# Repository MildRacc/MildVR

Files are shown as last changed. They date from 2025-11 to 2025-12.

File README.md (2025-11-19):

# MildVR

MildVR is a completely open-source VR headset with Windows, Linux, and macOS support in mind front the get-go. The goal of this project is to move away from the closed ecosystems of major VR companies like Meta. With the Quest lineup, Meta forces users to make accounts and limits PCVR usage to Windows by keeping their runtime proprietary. That means anyone using macOS or Linux is locked out completely. MildVR is different. It will use the open-source Monado runtime, which works across all three major desktop operating systems. It will never require and account, sign-in, or any proprietary software to function. Every part of the project, from the headset hardware, to the controllers, to the source code, will all be open for anyone to study, modify, or improve. My ultimate goal is to create a VR headset that anyone can build, understand, and use freely without being tied to any company, operating system, or proprietary software.

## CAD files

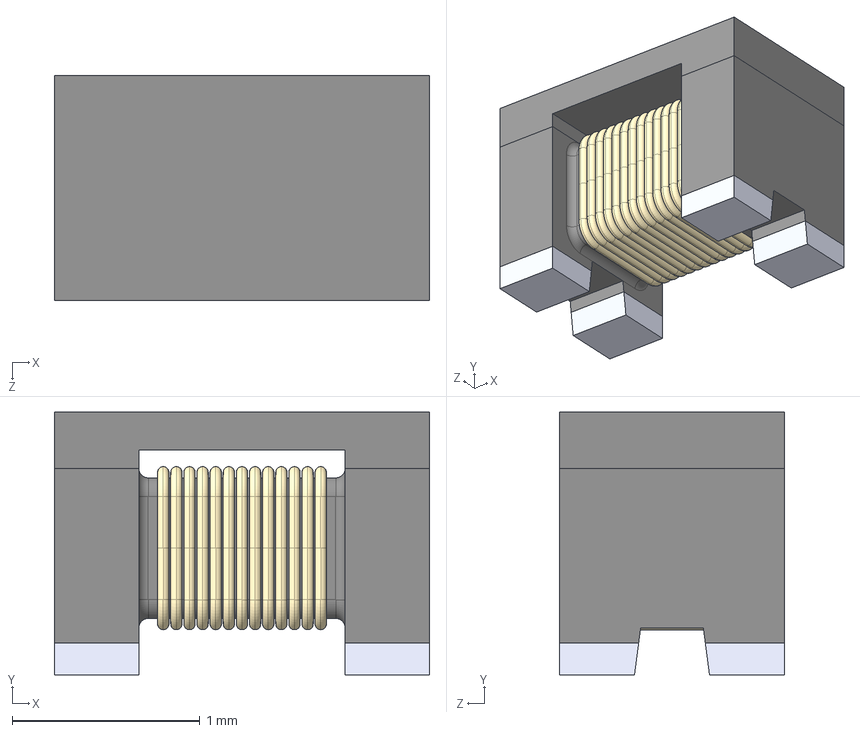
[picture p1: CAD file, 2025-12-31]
PCB/Imports/(CMC)DLW21SZ900HQ2L/DLW21SZ900HQ2L.step
2.00 x 1.40 x 1.20 mm

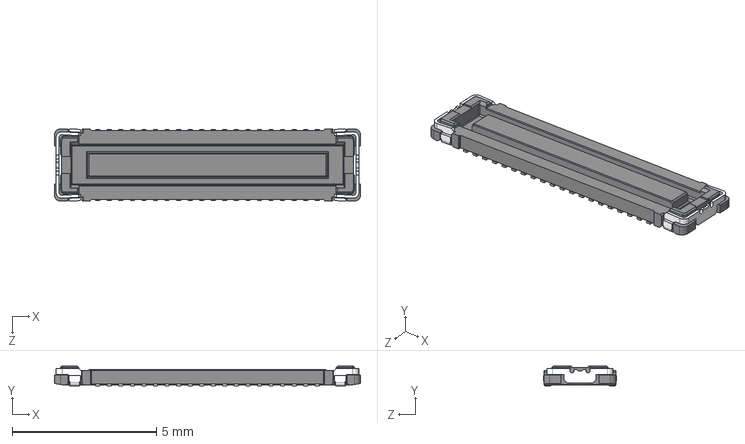
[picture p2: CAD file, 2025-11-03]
PCB/Imports/(DSI) WP7B-S040VA1-R6000/WP7B-S040VA1-R6000.step
10.6 x 0.68 x 2.51 mm

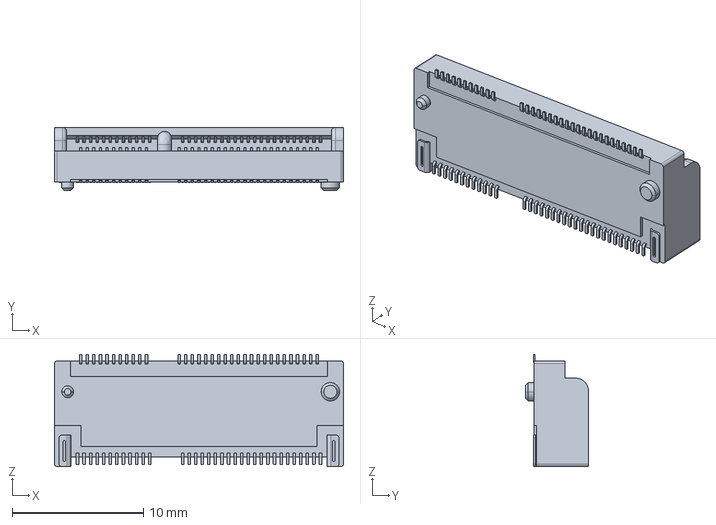
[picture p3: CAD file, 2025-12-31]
PCB/Imports/(PCIe)MDT420E03001/MDT420E03001.step
22.0 x 4.80 x 8.55 mm

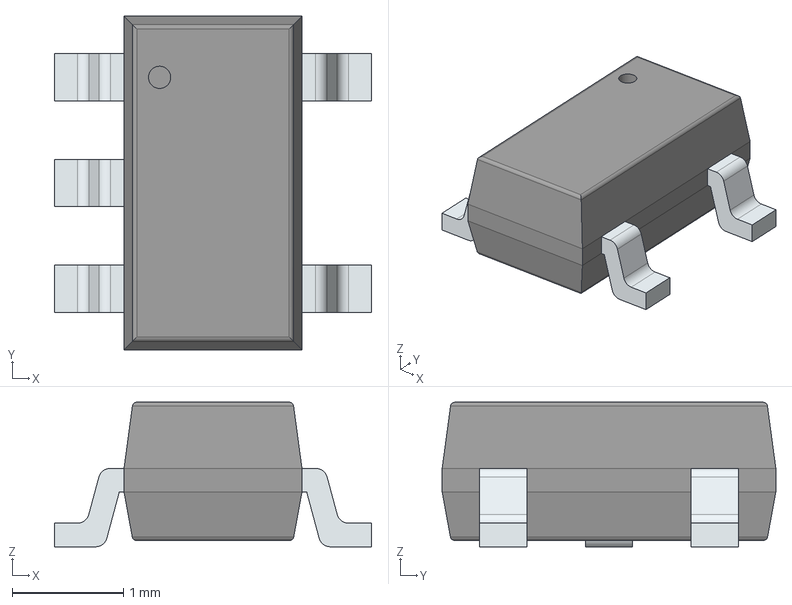
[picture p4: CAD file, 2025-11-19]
PCB/Imports/AP7365-WG-7/AP7365-WG-7/3D/AP7365-WG-7.stp
2.85 x 3.00 x 1.30 mm
PinsArrayL
PinsArrayR

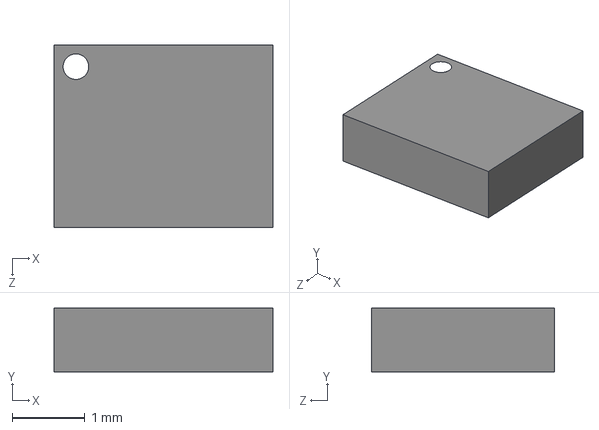
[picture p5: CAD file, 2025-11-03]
PCB/Imports/BMI270/BMI270.step
3.00 x 0.87 x 2.50 mm

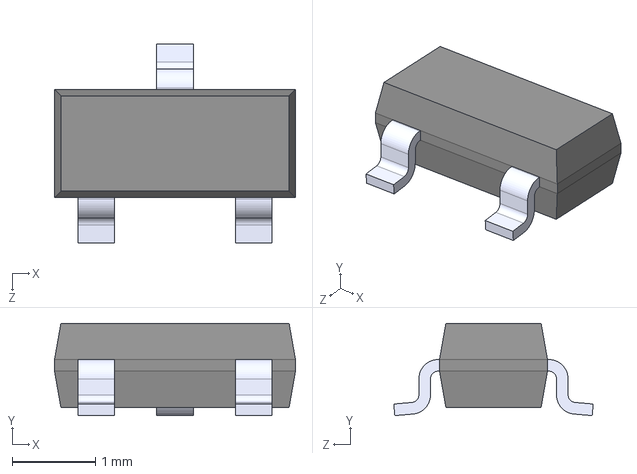
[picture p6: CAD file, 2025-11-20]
PCB/Imports/BSS138/BSS138.step
2.90 x 1.11 x 2.40 mm

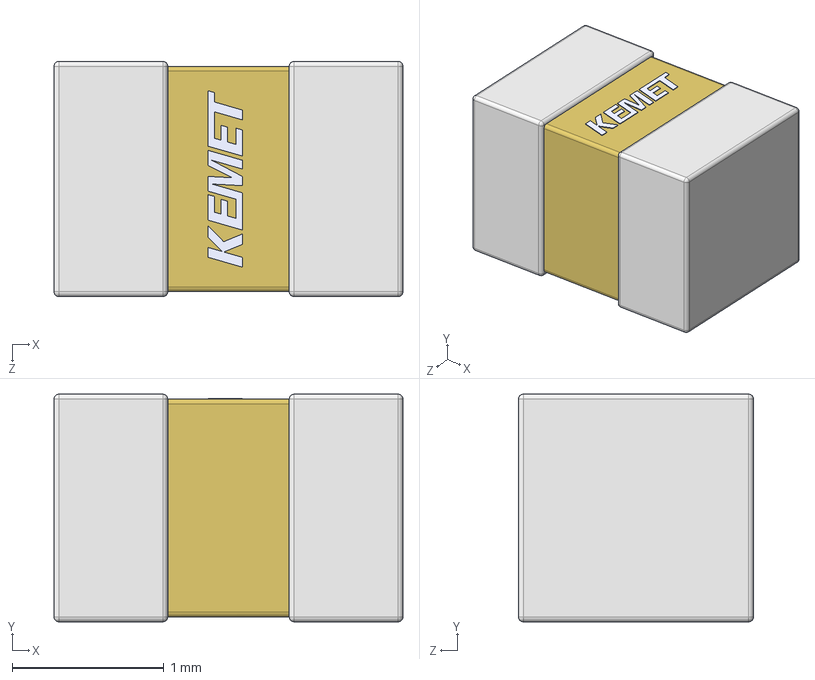
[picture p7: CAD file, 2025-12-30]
PCB/Imports/C0805J105K4RACAUTO(1uF)/C0805J105K4RACAUTO/3D/C0805J105K4RACAUTO.stp
2.30 x 1.50 x 1.55 mm

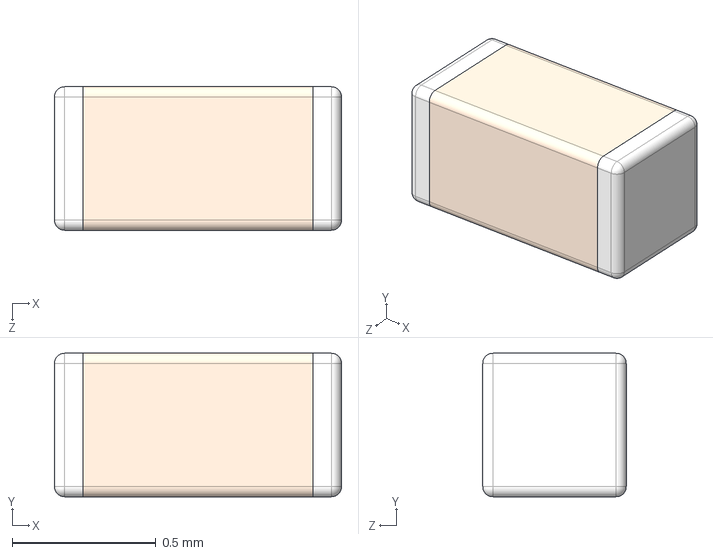
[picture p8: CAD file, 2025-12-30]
PCB/Imports/C1005NP01H102J050BA(1nF)/C1005NP01H102J050BA/3D/C1005NP01H102J050BA.stp
1.00 x 0.5 x 0.5 mm

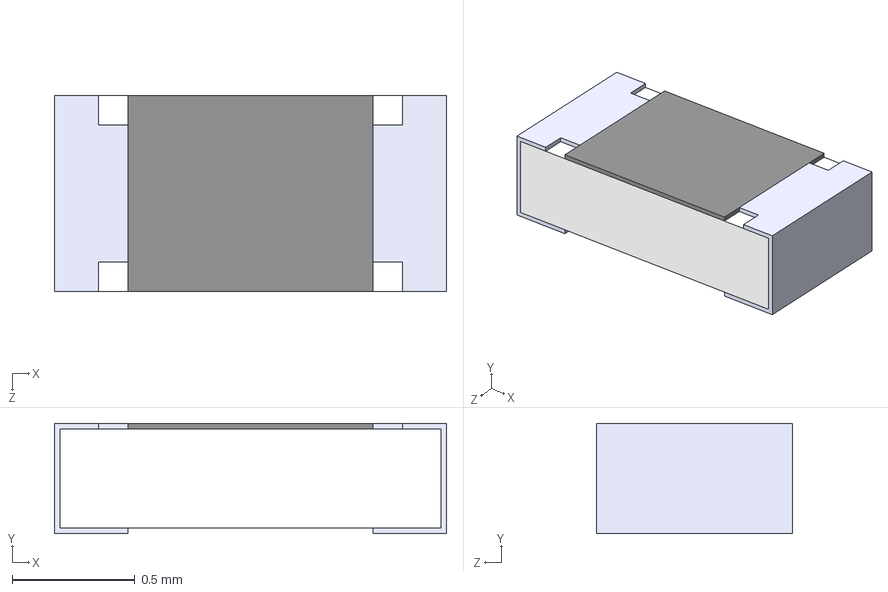
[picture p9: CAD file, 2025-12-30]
PCB/Imports/ERJU03J160V/ERJU03J160V.step
1.60 x 0.45 x 0.8 mm

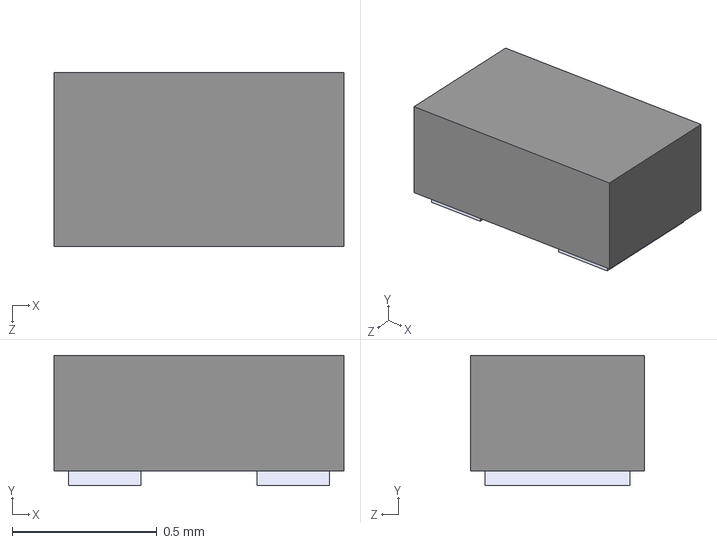
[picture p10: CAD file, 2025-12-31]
PCB/Imports/ESD401DPYR/ESD401DPYR.step
1.00 x 0.45 x 0.6 mm

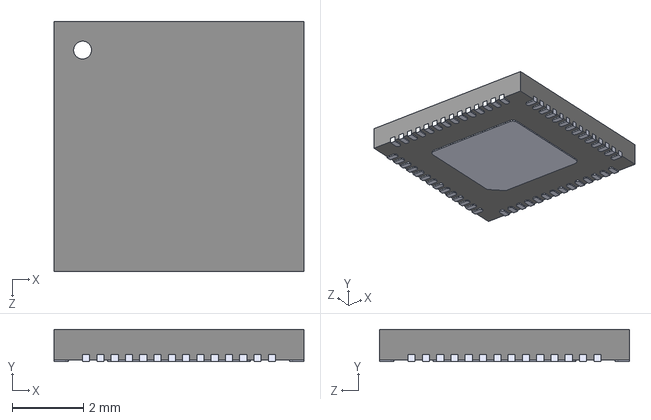
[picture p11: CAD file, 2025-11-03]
PCB/Imports/ESP32-S3/ESP32-S3.step
7.00 x 0.9 x 7.00 mm

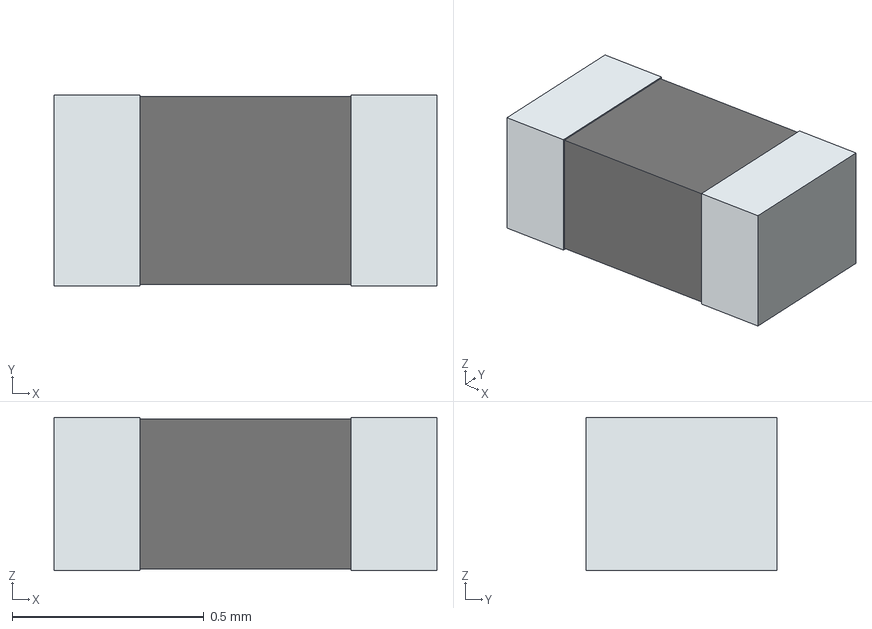
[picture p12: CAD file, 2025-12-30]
PCB/Imports/ESR01MZPF4701(4.7k)/ESR01MZPF4701/3D/ESR01MZPF4701.stp
1.00 x 0.5 x 0.4 mm
term1
term2

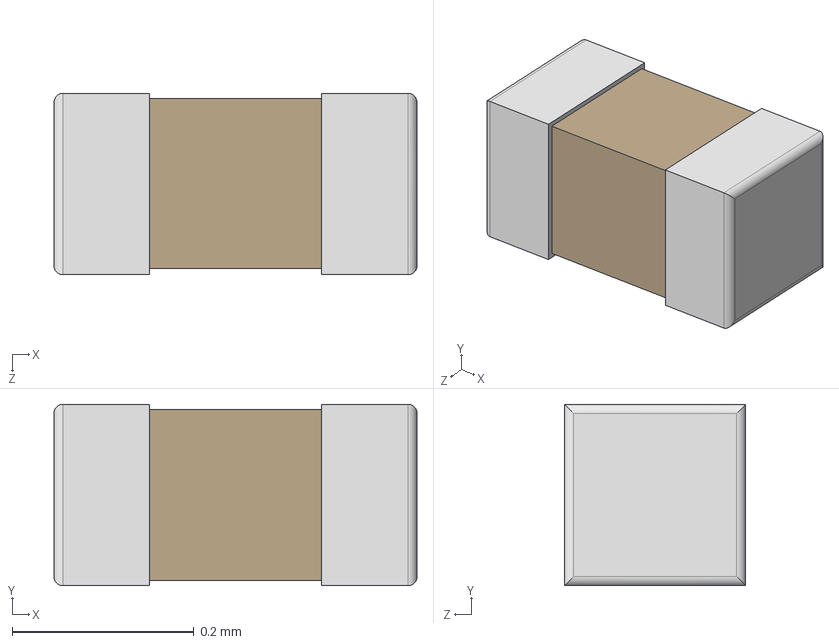
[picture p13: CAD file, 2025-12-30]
PCB/Imports/GRM022C81C103ME01L(10nF)/GRM022C81C103ME01L/3D/GRM022C81C103ME01L.stp
0.4 x 0.2 x 0.2 mm
GRM022R61C104ME05L_1
GRM022R61C104ME05L_2
GRM022R61C104ME05L_3

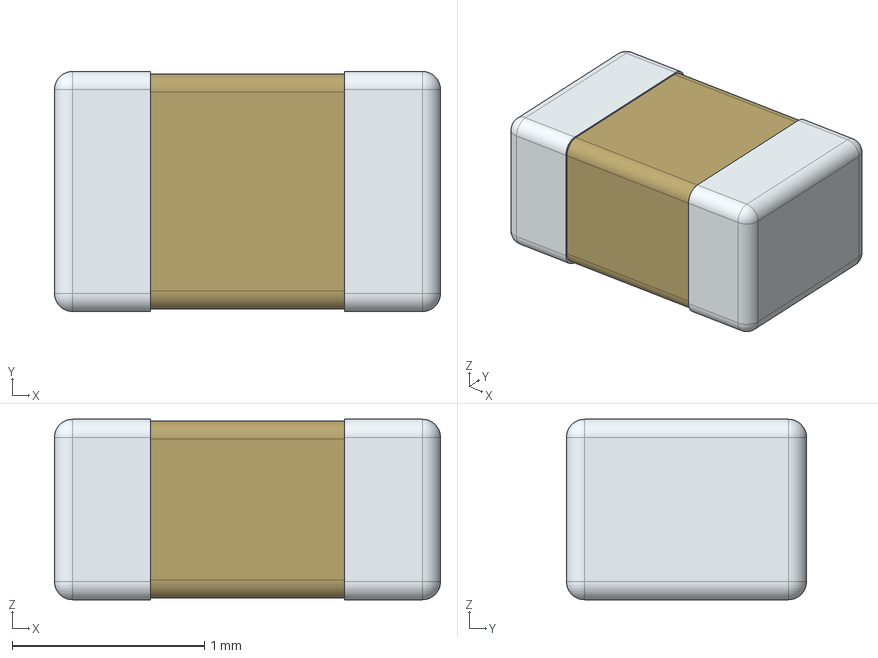
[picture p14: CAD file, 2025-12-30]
PCB/Imports/KAF21BR71H104JM(100nF)/KAF21BR71H104JM/3D/KAF21BR71H104JM.stp
2.01 x 1.25 x 0.94 mm

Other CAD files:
PCB/Imports/SFH_4556/SFH_4556.step
PCB/Imports/(CSI) 20539-050E-01/20539-050E-01.step
PCB/Imports/(Pump)LM27761DSGR/LM27761DSGR.step
PCB/Imports/BMI270/3D/BMI270.stp

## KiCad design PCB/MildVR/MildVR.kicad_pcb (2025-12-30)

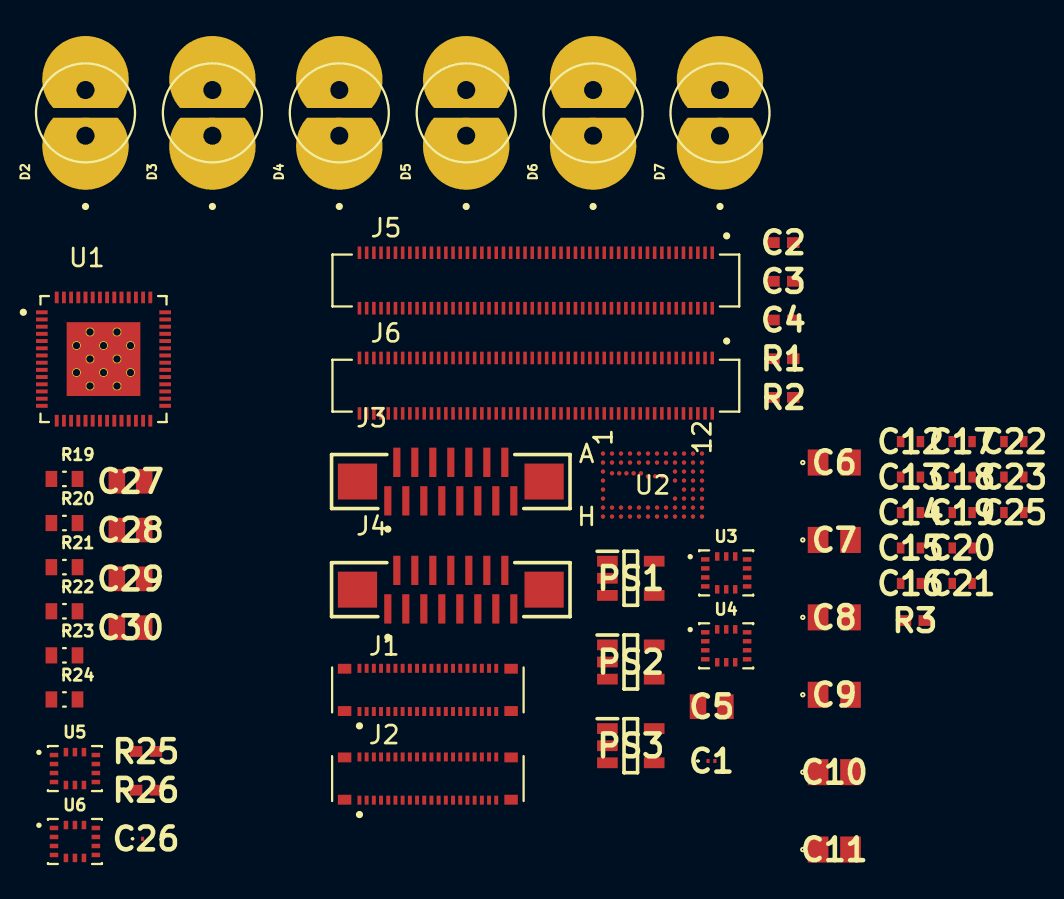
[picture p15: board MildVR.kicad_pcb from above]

Board: 2 copper layers, 61 parts (0 on the bottom side), 41 nets, no tracks yet.

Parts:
C1, C26: 10nF; GRM022C81C222KE01L
C2, C3, C4: 100nF; RESC1005X40N
C5, C27, C28, C29, C30: 100nF; CAPC2012X94L
C6, C7, C8, C9, C10, C11: 1uF; C0805
C12, C13, C14, C15, C16, C17, C18, C19, C20, C21, C22: 1nF; CAPC1005X55N
C23, C25: 100nF; CAPC1005X55N
D2, D3, D4, D5, D6, D7: LED; DIO_SFH_4556
J1, J2: WP7B-S040VA1-R6000; (DSI) WP7B-S040VA1-R6000
J3: CAM1; SAMTEC_ZF5S-15-03-T-WT
J4: CAM2; SAMTEC_ZF5S-15-03-T-WT
J5: GPIO; HIROSE_DF40C-100DS-0.4V_51_
J6: High Speed Serial; HIROSE_DF40C-100DS-0.4V_51_
PS1, PS2, PS3: AP7365-WG-7
R1, R2, R3, R25, R26: 4.7k; RESC1005X40N
R19, R20, R21, R22, R23, R24: 16; RES_ERJU03J160V
U1: ESP32-S3
U2: HMC6301BG46
U3, U4, U5, U6: BMI270

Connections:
1.2V: C11.2 (-), PS3.5 (OUT)
1.35V: C9.2 (-), C12.2 (-), C13.1 (+), C14.2 (-), C15.1 (+), C16.1 (+), C17.2 (-), C18.2 (-), C19.2 (-), PS2.5 (OUT), U2.A9 (VCCDIV), U2.A10 (VCCDIV), U2.A11 (VCCDIV), U2.A12 (VCCDIV), U2.B5 (VDDD), U2.B10 (VCCDIV), U2.B11 (VCCDIV), U2.B12 (VCCDIV), U2.C9 (VSSDIV), U2.C10 (VSSDIV), U2.C11 (VSSDIV), U2.C12 (VSSDIV), U2.F9 (VDDSYN), U2.G3 (VCCMIX), U2.G5 (VCCTRIP), U2.G7 (VSSVCO), U2.G8 (VSSVCO), U2.G9 (VCCVCO), U2.G10 (VCCVCO), U2.G12 (VDDSYN), U2.H2 (VCOLNA), U2.H3 (VCCIF), U2.H6 (VSSVCO), U2.H9 (VSSVCO), U2.H10 (VSSVCO), U2.H11 (VSSVCO), U2.H12 (VSSVCO)
2.7V: C7.2 (-), C20.1 (+), PS1.5 (OUT), R3.2 (-), U2.A5 (VCCBUF)
/1V8: J5.88, J5.90
/3V3: C1.2 (-), C2.1 (+), C3.2 (-), C4.1 (+), C5.1 (+), C6.2 (-), C8.2 (-), C10.2 (-), J3.15, J4.15, J5.84, J5.86, PS1.1 (IN), PS1.3 (EN), PS2.1 (IN), PS2.3 (EN), PS3.1 (IN), PS3.3 (EN), R1.1 (+), R2.1 (+), U3.1 (SDO), U3.5 (VDDIO), U3.8 (VDD), U3.12 (CSB), U4.5 (VDDIO), U4.8 (VDD), U4.12 (CSB)
/5V: J5.77, J5.79, J5.81, J5.83, J5.85, J5.87
/CAM0_C_P: J3.09, J6.42
/CAM0_D0_N: J3.02, J6.28
/CAM0_D0_P: J3.03, J6.30
/CAM0_D1_N: J3.05, J6.34
/CAM0_D1_P: J3.06, J3.08, J6.36
/CAM1_C_P: J4.06, J4.08, J4.09, J6.29
/CAM1_D0_N: J4.02, J6.15
/CAM1_D0_P: J4.03, J6.17
/CAM1_D1_N: J4.05, J6.21
/CAM_GPIO: J3.11, J4.11, J5.97
/CLK: J5.56, R1.2 (-), U3.13 (SCX), U4.13 (SCX)
/Right Controler/3V3: C26.2 (-), C27.1 (+), C28.1 (+), C29.1 (+), C30.2 (-), R19.2, R20.2, R21.2, R22.2, R23.2, R24.2, R25.1 (+), R26.1 (+), U1.2 (VDD3P3), U1.3 (VDD3P3), U5.1 (SDO), U5.5 (VDDIO), U5.8 (VDD), U5.12 (CSB), U6.5 (VDDIO), U6.8 (VDD), U6.12 (CSB)
/Right Controler/CLK: R26.2 (-), U5.13 (SCX), U6.13 (SCX)
/Right Controler/SDA: R25.2 (-), U5.14 (SDX), U6.14 (SDX)
/SCL0: J3.13, J5.80
/SDA: J5.58, R2.2 (-), U3.14 (SDX), U4.14 (SDX)
/SDA0: J3.14, J5.82
GND: C1.1 (+), C2.2 (-), C3.1 (+), C4.2 (-), C5.2 (-), C6.1 (+), C7.1 (+), C8.1 (+), C9.1 (+), C10.1 (+), C11.1 (+), C12.1 (+), C13.2 (-), C14.1 (+), C15.2 (-), C16.2 (-), C17.1 (+), C18.1 (+), C19.1 (+), C20.2 (-), C23.2 (-), C25.1 (+), J3.01, J3.04, J3.07, J3.10, J4.01, J4.04, J4.07, J4.10, J5.1, J5.2, J5.7, J5.8, J5.13, J5.14, J5.22, J5.23, J5.32, J5.33, J5.42, J5.43, J5.52, J5.53, J5.59, J5.60, J5.65, J5.66, J5.71, J5.74, J5.98, J6.7, J6.8, J6.13, J6.14, J6.19, J6.20, J6.25, J6.26, J6.31, J6.32, J6.37, J6.38, J6.44, J6.50, J6.55, J6.56, J6.61, J6.62, J6.67, J6.68, J6.73, J6.74, J6.79, J6.80, J6.85, J6.86, J6.91, J6.92, J6.97, J6.98, PS1.2 (GND), PS2.2 (GND), PS3.2 (GND), U2.B3 (GND), U2.B4 (GND), U2.B6 (GND), U2.B7 (GND), U2.C1 (GND), U2.C2 (GND), U2.C3 (GND), U2.C4 (GND), U2.C5 (GND), U2.C6 (GND), U2.D1 (GND), U2.D6 (GND), U2.D7 (GND), U2.D8 (GND), U2.F1 (GND), U2.G2 (GND), U2.G4 (GND), U2.H1 (GND), U2.H5 (GND), U3.6 (GNDIO), U3.7 (GND), U4.1 (SDO), U4.6 (GNDIO), U4.7 (GND)
GND1: C26.1 (+), C27.2 (-), C28.2 (-), C29.2 (-), C30.1 (+), D2.1 (K), D3.1 (K), D4.1 (K), D5.1 (K), D6.1 (K), D7.1 (K), U1.57 (GND), U5.6 (GNDIO), U5.7 (GND), U6.1 (SDO), U6.6 (GNDIO), U6.7 (GND)
unnamed: C21.1 (+), U2.B9 (EXTFIL_N)
unnamed: C21.2 (-), U2.B8 (EXTFIL_P)
unnamed: C23.1 (+), U2.G11 (VCCRCAP)
unnamed: C25.2 (-), U2.G6 (VREGOUT)
unnamed: D2.2 (A), R24.1
unnamed: D3.2 (A), R23.1
unnamed: D4.2 (A), R22.1
unnamed: D5.2 (A), R21.1
unnamed: D6.2 (A), R19.1
unnamed: D7.2 (A), R20.1
unnamed: J1.S1 (SHIELD), J1.S2 (SHIELD), J1.S3 (SHIELD), J1.S4 (SHIELD)
unnamed: J2.S1 (SHIELD), J2.S2 (SHIELD), J2.S3 (SHIELD), J2.S4 (SHIELD)
unnamed: PS1.4 (ADJ), R3.1 (+)
unnamed: U2.E10 (VSSCP), U2.E11 (VSSCP)
unnamed: U2.D9 (VSSLPF), U2.D10 (VSSLPF), U2.D11 (VSSLPF), U2.D12 (VSSLPF)
unnamed: U2.F10 (VSSREF), U2.F11 (VSSREF)

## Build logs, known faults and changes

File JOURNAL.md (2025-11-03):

<!--
  ===================    !!READ THIS NOTICE!!   ====================
  DO NOT edit this file manually. Your changes WILL BE OVERWRITTEN!
  This journal is auto generated and updated by Hack Club Blueprint.
  To edit this file, please edit your journal entries on Blueprint.
  ==================================================================
-->

## 10/28/2025 - Electronics Research  

Because I want my headset to be a wireless PCVR headset, I need to transmit and receive data incredibly fast. DisplayPort 1.2 transmits 21.6 Gib/s, and I'd like each eye to be about 2k120fps. I found WiGig transceivers to be the best option for this, and the particular models I'm going to use are the [HMC6300/6301](https://www.mouser.com/c/?marcom=138219097) chips.

I need to have a chip to decode and encode DisplayPort data going to and fro the transmitter and receiver, and the [ANX7497](https://www.analogix.com/en/products/re-timersrepeaters/anx7497) seems to be the best option for what I need. It can also compress and decompress DisplayPort data, making video transmission faster, and less of a hassle.

For the displays, I have a lot of options. All I want is 2k120fps. A lot of companies sell displays catered to VR/AR on sites like Alibaba and Aliexpress, and I have found tons of displays that meet my needs.

For the inside-out tracking, I plan to use a dual [OV9281](https://docs.arducam.com/Raspberry-Pi-Camera/Native-camera/Global-Shutter/1MP-OV9281-OV9282/) setup mounted into the front of the headset. In the controllers I will have an array of NIR (Near-Infrared) LEDs in a configuration similar to that of the Oculus Rift S controllers. The purpose of these NIR LEDs is to give the cameras points to track, and by arranging them in a certain configuration will allow me to determine the transform of the entire controller.

(Image from [iFixit](https://www.ifixit.com/Teardown/Oculus+Rift+CV1+Teardown/60612))

This image shows the LED configuration of the original Oculus Rift. Having a recognizable LED configuration makes tracking more precise.

The controllers and headset will all contain two [BMI270](https://www.mouser.com/new/bosch/bosch-sensortec-bmi270/) IMUs. The purpose of having two IMUs is for redundancy, reliability, noise reduction, and improved orientation tracking. Oculus and other high-end controllers typically use a single IMU in their controllers, but due to the fact that my inside-out tracking algorithms are likely not going to be on-par with theirs, I feel it is necessary to compensate by making IMU readings more accurate.  

## 11/2/2025 - ECAD Sourcing & Controller Thoughts  

I have found some ECAD models online for the connectors, and SMD components which will go on the motherboard of my headset. While researching datasheets and CAD models for parts, I discovered that Analogix does not manufacture or sell the ANX7497. Instead, they redirect to their distributors who also do not list the ANX7497 on their websites. I emailed their North American distributor to get information on the ANX7497, but in the meantime, I will be using the MCDP6150C1 instead. Below is a list of links to the CAD files I have found for the components that I know I will need.

[ESP32-S3](https://www.snapeda.com/parts/ESP32-S3/Espressif%20Systems/view-part/?ref=search&t=ESP32-S3&ab_test_case=b)
[HMC6300BG46P7 (Transmitter)](https://www.digikey.com/en/models/6072652?tab=ultralibrarian)
[HMC6301BG46 (Receiver)](https://www.digikey.com/en/models/6072653?tab=ultralibrarian)
[MCDP6150C1 (ANX7497 Replacement)](https://www.snapeda.com/parts/MCDP6150C1/Kinetic%20Technologies/view-part/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)
[BMI270 (IMU)](https://www.snapeda.com/parts/BMI270/Bosch%20Sensortec/view-part/?ref=search&t=BMI270)
[CSI Connectors](https://www.snapeda.com/parts/20539-050E-01/I-PEX/view-part/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)
[Display Connector](https://www.snapeda.com/parts/WP7B-S040VA1-R6000/JAE%20Electronics/view-part/?ref=search&t=WP7B-S040VA1)
Display connector goes to [these displays](https://www.alibaba.com/product-detail/2-9-Inch-1440x1440-Square-HMD_1600064398346.html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)

These displays do not have any CAD files that I could find, but this image is available on the AliBaba listing, and is what I will be referencing going forward.

I wanna take a second to talk about why I chose some of the parts I did, starting with the ESP32-S3. I considered using a Raspberry Pi CM4, but after some research, I didn't like how much space it took up. I decided that it would make more sense to go with an SoC. The first SoC I considered was one of the LPC11Uxx SoCs, but I decided that due to the lack of knowledge or online support for this processor, it was a poor contender for the main CPU for the headset. Instead I chose the ESP32-S3 due to how well known the ESP32 SoCs are, as well as the fact that it has built in WiFi, Bluetooth, and how much storage it has. This SoC should be easy to program in Rust, and easy for beginners to modify in an IDE like ArduinoIDE or PlatformIO.
The reason for picking the BMI270 is that previous IMUs, such as the MPU6500, 6050, and 9250 have been discontinued, and are now considered obsolete. The BMI270 is a newer alternative, and it is an all-around a better IMU, with its only downside, being that it requires configuration and more careful calibration than the MPU IMUs.
Since the ANX7497 is not available in a consumer-friendly way, I had to find an alternative. The closest chip I could find to the ANX7497 was the MCDP6150C1. It has very subtle differences to the ANX7497, but from what I've read, it can do exactly what I need.

I also want to share some of my thoughts on what I want to do about the controllers:
I don't have any.
While I do want this headset to have accompanying controllers, I don't want to think about them at the moment. The reason is that they're easy to make.
The controllers would, more or less, function identically to a standard Oculus Rift controller. They will have analog sticks, regular triggers, grip triggers, and face buttons. The only difference is that the controllers will also have two BMI270 IMUs for spatial tracking. There's not a whole lot to think about on this front.

I also plan to make the controllers wireless (of course), and use Bluetooth. My Oculus Rift S controllers use Bluetooth, and I have never had any issues that a simple battery swap couldn't fix, so using Bluetooth will make everything incredibly easy.

Now with all that being said: I do want other non-conventional or homemade controllers to work as well. I like the idea of being able to build a VR glove, like the [LucidVR](https://github.com/LucidVR/lucidgloves) gloves, and have it work perfectly, hopefully without drivers.

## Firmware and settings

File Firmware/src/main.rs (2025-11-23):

use rppal;
use tokio;
use bluer::{Adapter, AdapterEvent};

mod bluetooth;
mod controllers;


#[tokio::main]
async fn main() {

    println!("Test");
    
    
    let systems = tokio::spawn(systems_handler());
    let controllers = tokio::spawn(controller_handler());
    let host_comms = tokio::spawn(host_communication_handler());
    let slammer = tokio::spawn(slam());

}


async fn systems_handler()
{
    loop {
        
    }


}


async fn controller_handler()
{

}

async fn host_communication_handler()
{

}

async fn slam()
{

}

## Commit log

2025-11-03 Create KiCad project
    [20539-050E-01.step, BMI270.step, ESP32-S3.step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]
2025-11-03 Begin wiring of BMI270s
    [MildVR.kicad_sch]
2025-11-19 [PCB] Routing Gyros and Receiver power
    [AP7365-WG-7.stp, MildVR.kicad_sch]
2025-11-20 [PCB] Reciever Setup Routing + Organization
    [BSS138.step, MildVR.kicad_sch]
2025-11-22 [PCB] Replace ESP32-S3 with Raspbery Pi CM4
    [CM4IOv5-B_Cu.gbr, CM4IOv5-B_Mask.gbr, CM4IOv5-Edge_Cuts.gbr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]
2025-12-30 Organization and stuff
    [BMI270.stp, C0805J105K4RACAUTO.stp, C1005NP01H102J050BA.stp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]
2025-12-31 Replaced HMC6301 with M.2 PCIe Key E
    [DLW21SZ900HQ2L.step, ESD401DPYR.step, LM27761DSGR.step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]
2026-02-13 Replace CM4 connectors with CM3588 ones
    [MildVR.kicad_sch]
